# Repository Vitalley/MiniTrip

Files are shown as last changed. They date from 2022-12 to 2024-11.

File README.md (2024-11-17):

# MiniTrip
Miniature trip computer for Audi 80/100/200/A6C4 on PIC16F1847 with display SH1109/SSD1306/SSD1309 OLED controllers 128x64 pixel

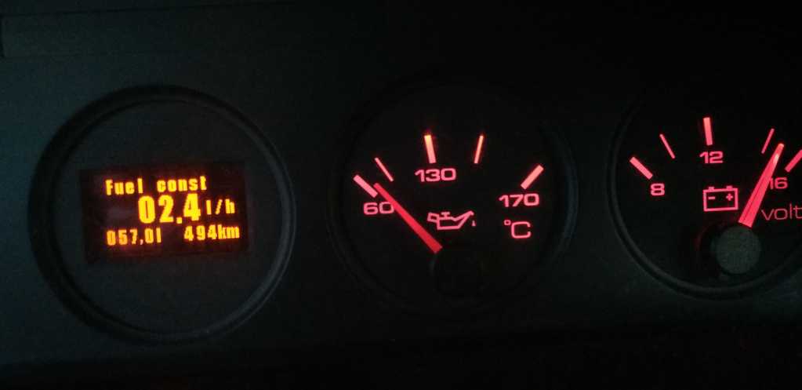
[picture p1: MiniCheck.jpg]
MiniCheck

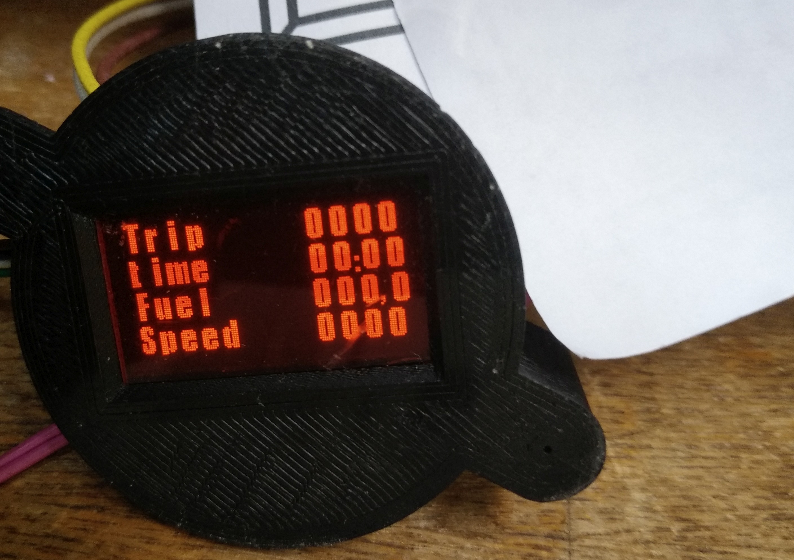
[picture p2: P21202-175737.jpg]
Test View


Main feutures:
- fuel consumption;
- speedometer;
- odometer;
- hour counter;
- on-board voltage;
- fuel level.

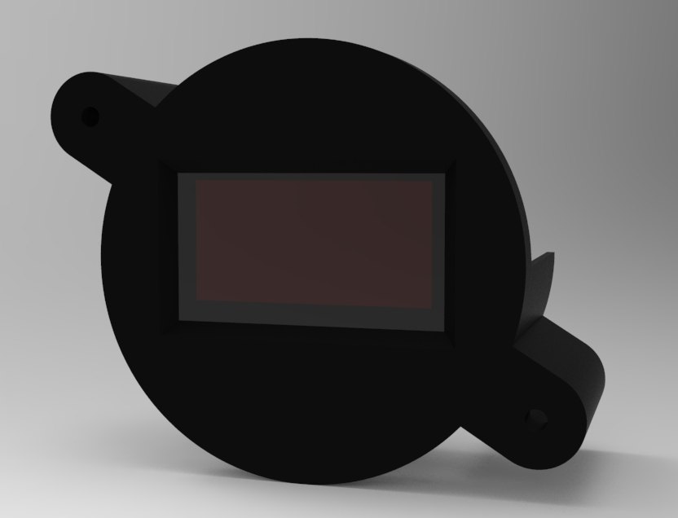
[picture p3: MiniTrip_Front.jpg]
Front

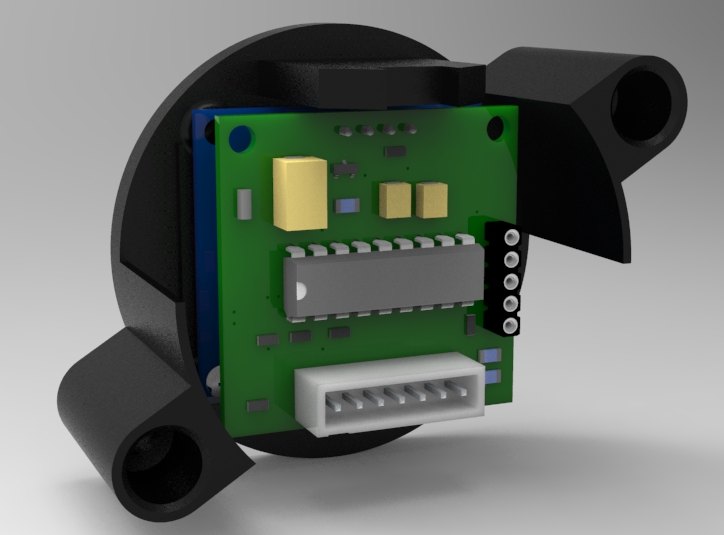
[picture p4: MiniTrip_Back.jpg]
Back


Testing on Audi A6/100 C4 with Digifant ECU ABK motor and AAD Motronic.

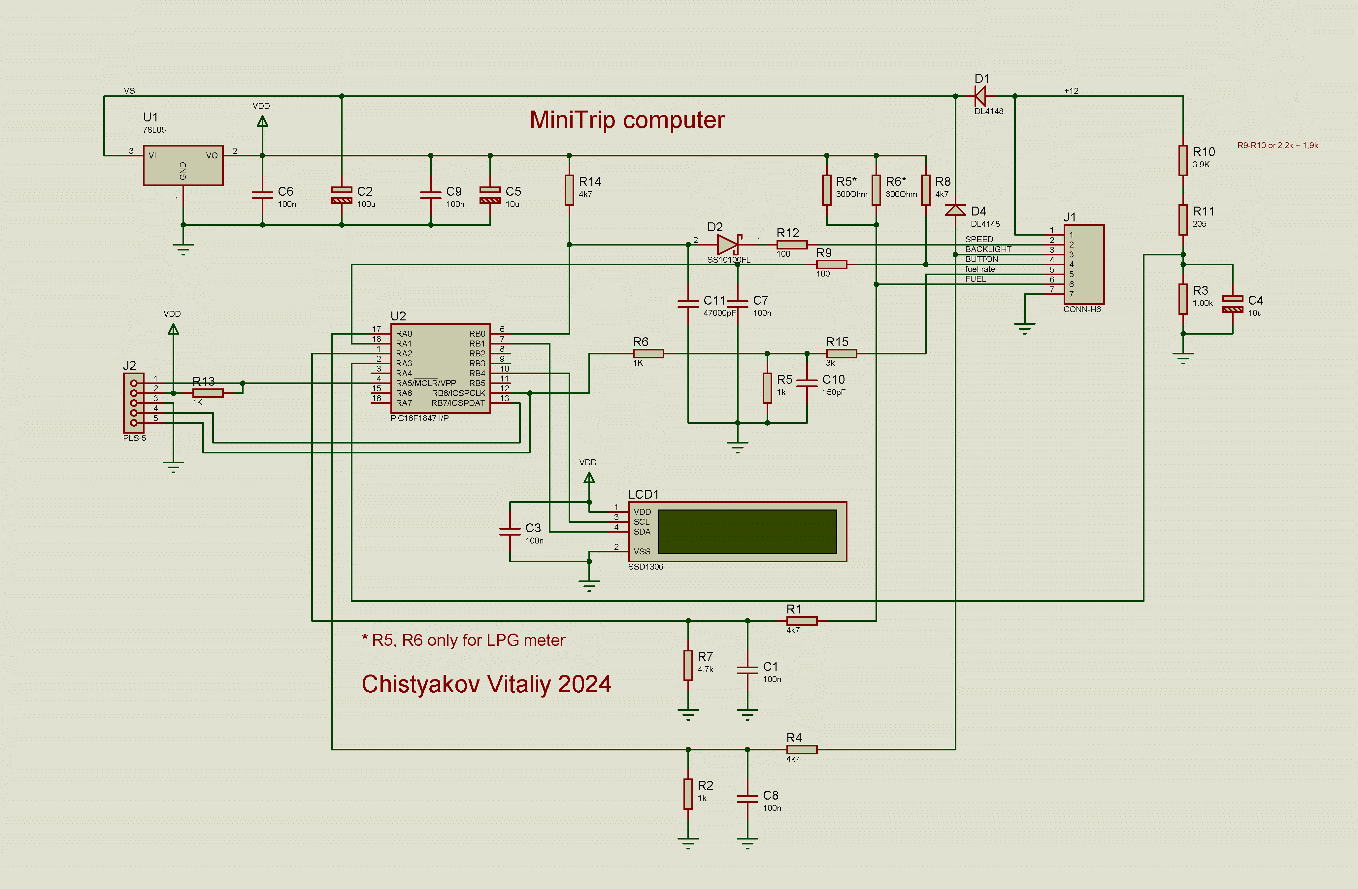
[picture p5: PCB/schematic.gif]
Schem


Fuel level sensor

|Fuel	|	Voltage|
|-----	|---		|
|12L	| 	- 2,4v|
|20L	|	- 3,0v|
|40L	|	 - 3,8v|
|60L	|	 - 4,5v|
|80L	|	 - 5,5v|

Project create in MPLAB IDE v8.92 from Mictochip and XC8 Compiler

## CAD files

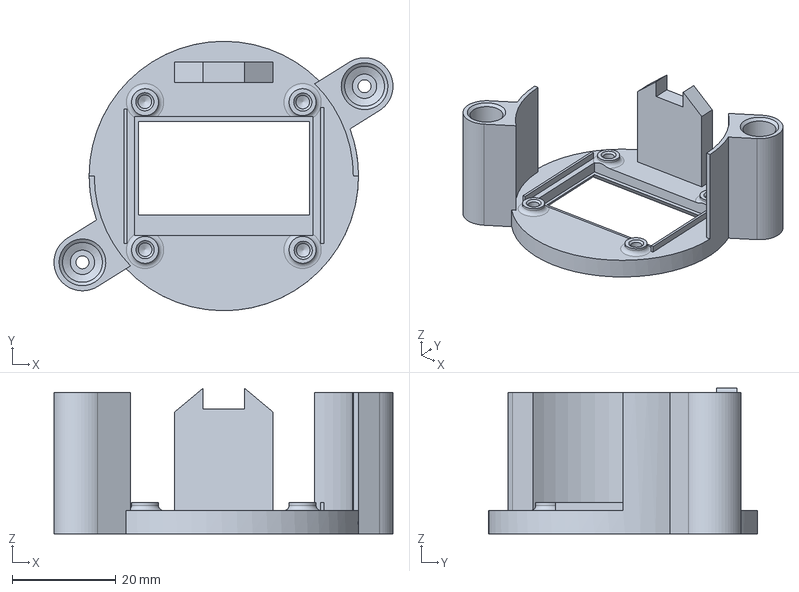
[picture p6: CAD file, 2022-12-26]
CAD/OLED_mask.stp
65.4 x 52.0 x 28.1 mm

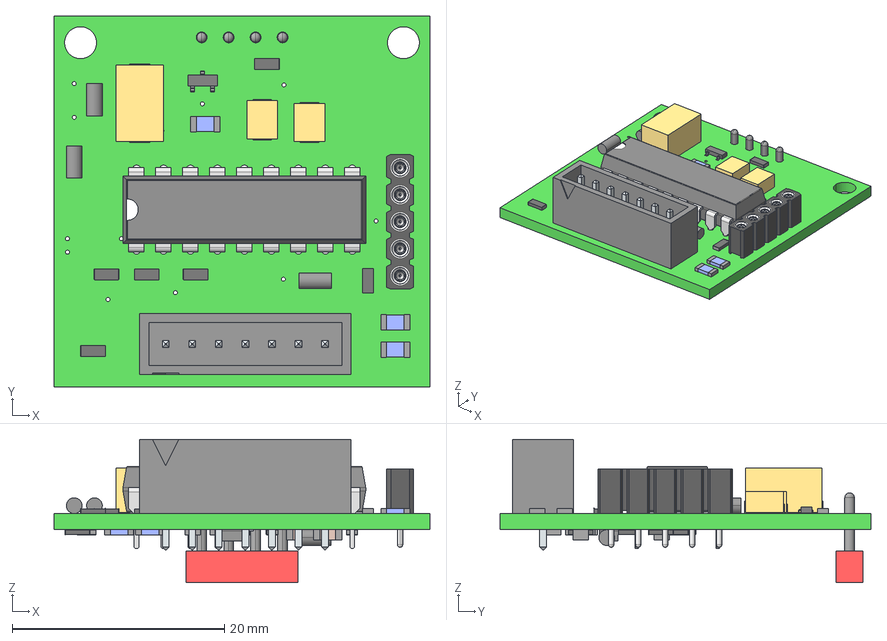
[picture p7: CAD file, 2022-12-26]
CAD/MiniTrip.STEP
35.4 x 34.9 x 13.5 mm
Layer_1
Pin_1 x 30
Pin_2 x 30
Pin_3 x 2
Pin_4
=>[0:1:1:2] x 2
=>[0:1:1:3]
=>[0:1:1:4]
=>[0:1:1:5]

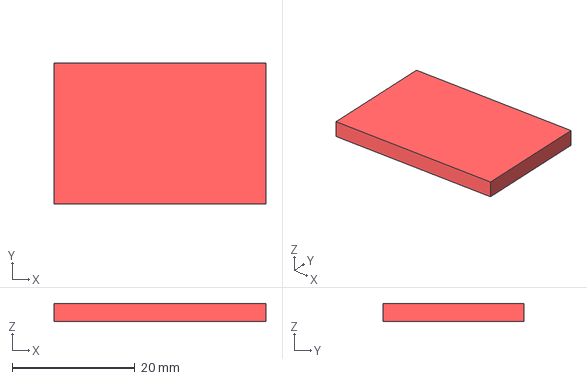
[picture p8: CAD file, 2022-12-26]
CAD/Glass.stp
34.5 x 23.0 x 3.00 mm

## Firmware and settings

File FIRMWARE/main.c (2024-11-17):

#include <xc.h>
//#include <stdio.h>
#include "../SH1106/OLED.h"
#include "screens.h"
#include "button.h"
#include "config.h"
#include "screen.h"
#include "I2C.h"
#include "EEPROM.h"
//#include "median.c"
/*
fuel -  расход топлива 0.1литр в час
speed - скорость км/ч*2
impavr - израсходовано топлива за поездку 25000/литр
triptime - время в пути Сек
fueltank - количество топлива в баке *10 л
*/
unsigned int  fuel, speed, speedcnt, fueltank, volt, volt_array[array_size_voltage+2], fuel_array[array_size_fuel+2];
unsigned long int impavr, trip, triptime, totalodo, totaltime, TO1_ODO, TO1_TIME, TO2_ODO, TO2_TIME;
bit turn = 0, motoron = 0, saveEEDATA = 0, bri;
static unsigned int TMR1_OLD_DATA = 0;
char scrn, mscr, mkey;
void init(void)
{
    LATA = 0x00;
    LATB = 0x00;
    TRISA = 0b00011111;
    TRISB = 0b01111111;
    ANSELB = 0x00;
    ANSELA = 0b0001101;
    WPUB = 0x00;
    WPUA = 0x00;
    OPTION_REGbits.nWPUEN = 1;
    APFCON0 = 0x00;
    APFCON1 = 0x00;
//	CPSCON0 = 0x00;

    OSCCON = 0x70;
    BORCON = 0x00;
//     OSCTUNE = 0x00;
     WDTCON = 0x16;
    while(PLLR == 0)
    {
	    CLRWDT();
    }
    I2CInit();
    OPTION_REG = (unsigned char)((OPTION_REG & 0xC0) | (0xD7 & 0x3F)); 
    TMR0 = 176;   
     //T1GSS T1G_pin; TMR1GE disabled; T1GTM disabled; T1GPOL low; T1GGO done; T1GSPM disabled; 
    T1GCON = 0x00;
    TMR1H = 0x00;
    TMR1L = 0x00;
    PIR1bits.TMR1IF = 0;  
    T1CON = 0b10000011; 
    T1GCON = 0;
    // Set TMR2 to the options selected in the User Interface
    PR2 = 0x03;
    TMR2 = 0x00;
    // Clearing IF flag before enabling the interrupt.
    PIR1bits.TMR2IF = 0;
    // Enabling TMR2 interrupt.
    PIE1bits.TMR2IE = 1;
    // T2CKPS 1:64; T2OUTPS 1:1; TMR2ON on; 
    T2CON = 0x07;
 
    
    ADCON1 = 0xF0;
    ADRESL = 0x00;
    ADRESH = 0x00;
    ADCON0 = 0x01;


    INTCONbits.TMR0IF = 0;
    INTCONbits.TMR0IE = 1;
    
    
    EEREADDATA();
    CLRWDT();
    _delay(1999);
    OLEDinit(OLED_Adr,127,62);    
    OLEDbrightness(OLED_Adr,0xF0); 
    bri = 1;
    
    
    // Enable IOCI interrupt 
    INTCONbits.IOCIE = 1; 
    INTCONbits.GIE = 1;
    INTCONbits.PEIE = 1;
}
unsigned int GET_ADC(char channel)
{
	__delay_us(100);
	ADCON0bits.CHS = channel;
	__delay_us(100);
	ADCON0bits.GO_nDONE = 1;
	while (ADCON0bits.GO_nDONE){}
	return ((unsigned int)((ADRESH << 8) + ADRESL));
}
unsigned int SMA_filter(unsigned int a,unsigned  int* Massive, unsigned char array_size)
{
	char n=Massive[array_size];
	if (n>=(array_size)) n=0;	
	Massive[n]=a;
	Massive[array_size]=n+1;
	if (Massive[array_size+1] < array_size-1) {Massive[array_size+1]++;return (a);}
	a=0;
	for(char j=0;j<array_size;j++) 
	{
		a=a+Massive[j];
	}
	return (unsigned int)a/array_size;
}
unsigned int map(unsigned int x, unsigned int in_min, unsigned int in_max, unsigned int out_min, unsigned int out_max)
{
  return (x - in_min) * (out_max - out_min) / (in_max - in_min) + out_min;
}
void main(void)
{
	static char seladc;
	init();
	fueltank = 100;
    _delay(999);CLRWDT();
 	oledClear(OLED_Adr);
 	screen0();
 	for (int bra=0;bra<5600;bra++)
	{
		_delay(1999);CLRWDT();	
	}

 	mscr = 0;speed=0;fuel=0;seladc=0;


while(1)
{
	CLRWDT();
switch (seladc)
{
case 0:	if (GET_ADC(0) > 200) 
	{
		if (bri !=0 ) {OLEDbrightness(OLED_Adr,0x00); bri = 0;}
	}	 
	else 
	{
		if (bri != 1 ) {OLEDbrightness(OLED_Adr,0xFF); bri = 1;}
		
	}
	seladc++;	
	break;
case 1:	volt = SMA_filter(GET_ADC(3), volt_array, array_size_voltage);
	seladc++;
	break;
case 2:	fueltank = SMA_filter(GET_ADC(2), fuel_array, array_size_fuel);
	//fueltank = Wquick_select_median(fuel_array, array_size_fuel);
	fueltank = fueltank - ft_sdd;
	//fueltank = 183;
	fueltank = (fueltank * (unsigned long int)ft_mult)/256;
	if (fueltank < 1000) fueltank = 1000 - fueltank; else fueltank = 0;
	if (fueltank > 999) {fueltank = 999;}
	seladc=0;
	break;
default: seladc=0;
}
	if (saveEEDATA) {EEWRITEFATA(); saveEEDATA=0;}
	if (speed>10) turn=1; else turn=0;
	if (fuel>1) motoron=1; else motoron=0;
CLRWDT();
	switch (mscr)
	{
	case 0: 	
	
		if (turn)
		{
			if (scrn != 1)oledClear(OLED_Adr);
			screen1();
				
		}
		
		else
		
		{
			if (motoron)
			{
		 	 	if (scrn != 2)oledClear(OLED_Adr);
				screen2();
			 		
			}
		 	else
			{
		 		if (scrn != 4)oledClear(OLED_Adr);
				screen4();
			}
		
		}
		break;
// Текущая скорость движения	
	case 1:	
		if (!turn) 	
		{ 
			if (!motoron) {mscr++; break;}
		}
		if (scrn != 3) oledClear(OLED_Adr);
		screen3();
		break;
// Общая сводка о пройденом пути	
	case 2:
		if (!turn)
		{ 
			if (!motoron) {mscr++; break;}
		}	
		if (scrn != 4) oledClear(OLED_Adr);
		screen4();
		break;
// Бортовое напряжение	
	case 3:
		if (volt<40) {mscr++; break;}
		if (scrn != 6) oledClear(OLED_Adr);
		screen6();
		break;
//	Уровень топлива в баке и остаток пути	
	case 4:
		if (volt<10 || fueltank==0) {mscr++; break;}
		if (scrn != 7) oledClear(OLED_Adr);
		screen7();
		break;
// TO1	
	case 6:
		if (turn) {mscr++; break;}
		if (scrn != 8) oledClear(OLED_Adr);
		screen8();
		break;
// TO2	
	case 7:
		if (motoron) {mscr++; break;}
		if (scrn != 9) oledClear(OLED_Adr);
		screen9();
		break;
// Общий пробег
	case 5:
		if (motoron) {mscr++; break;}
		if (scrn != 5) oledClear(OLED_Adr);
		screen5();
		break;	
	default:
		scrn = 0;
	}
	 for (int bra=0;bra<24;bra++)
		{
			_delay(30000);CLRWDT();
			mkey = GetButton();
		
			if (mkey == 2)
			{ 
				if (mscr == 6)
				{
					screen11();
					for (unsigned char bra=0;bra<250;bra++)
					{
						mkey = GetButton();
						_delay(40000);
						if (mkey == 1) {EETO1RESET();}
					}
				}
				else if (mscr == 7) 
				{
					screen12();
					for (unsigned char bra=0;bra<250;bra++)
					{
						mkey = GetButton();
						_delay(40000);
						if (mkey == 1) {EETO2RESET();}
					}		
				}
				else 
				{
					screen10();
					for (unsigned char bra=0;bra<250;bra++)
					{
						mkey = GetButton();
						_delay(40000);
						if (mkey == 1) {EETRIPRESET();}
					}			
				}
			}
			else if (mkey == 1) mscr++;
			
			if (mscr > 7) mscr=0;	
		}
}
}


void TMR0_ISR(void)
{
    static unsigned int CountSeconds = 0, Count7n2Seconds = 0, CountSPD = 0;
    static unsigned char CountTripTime;
    // callback function - called every 391th pass
    //	 Секундный счётчик
    if (++CountSeconds >= 391)
    {
	CountSeconds=0;
	// 30 Секундный счётчик
	if (++CountTripTime >= 30)
    	{
		if (fuel>1 || speed>1)
		{
			triptime++;
			totaltime++;
			TO1_TIME++;
			TO2_TIME++;
		}
		CountTripTime=0;
		saveEEDATA=1;
    	}
	
    }
// Счётчик для измерения расхода топлива
    if (++Count7n2Seconds >= 563)//563 при 25000 имп/литр
    {
// Код не вместился в память
//	char TMPH, TMPL;
//	do
//	{
//		TMPH = TMR1H;
//		TMPL = TMR1L;
//	}
//	while (TMPH == TMR1H);
//	unsigned int TMR_DATA = TMPH <<8 + TMPL;
	unsigned int TMR_DATA = TMR1;
	unsigned int FUEL = TMR_DATA - TMR1_OLD_DATA;
	TMR1_OLD_DATA = TMR_DATA;
	fuel = FUEL;
	impavr+=FUEL;
	Count7n2Seconds=0;
    }
// Счётчик скорости движения
    if (++CountSPD >= 698)
    {
	CountSPD = 0; 
	speed = speedcnt;
	speedcnt = 0;
    }
}
void TripCounter(void)
{
    static volatile unsigned int CountKM = 0;
    speedcnt++;
    if (++CountKM >= 409) // 100 метровый счётчик
    {
	trip++; 
	totalodo++;
	TO1_ODO++;
	TO2_ODO++;
	CountKM = 0;
    }
}
void interrupt isr(void)
{
   if(INTCONbits.INTF)
    {
	    INTCONbits.INTF = 0;
	    INTCONbits.INTE = 0;
	    T2CONbits.TMR2ON = 1;
	       	if (OPTION_REGbits.INTEDG) 
		        {
			        TripCounter();
			        OPTION_REGbits.INTEDG = 0;

			     }
	        else     
		        {
			        OPTION_REGbits.INTEDG = 1;
	        	}
	}
    else 
    if(PIR1bits.TMR2IF)
    {
    		PIR1bits.TMR2IF = 0;
    		T2CONbits.TMR2ON = 0;
    		INTCONbits.INTE = 1;
			TMR2 = 0;
    }
    else 
	if(INTCONbits.TMR0IF)
	{
		TMR0 = 176;
		INTCONbits.TMR0IF = 0;
		TMR0_ISR();
	}


}

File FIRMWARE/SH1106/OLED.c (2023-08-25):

#include <xc.h>
//#include <stdio.h>
#include "../I2C.h"
#include "OLED.h"
#define OLED_Adr 0x3C
#include "Font16x8.h"
#include "Font40x20.h"
void oledCommand(unsigned char comm, unsigned char Adr) {
	StartI2C();
	if (WriteI2C( (Adr<<1) & 0xFE)!=0) return;//Начинаем передачу команд устройству с адресом Adr.
  	WriteI2C(0x00);//Сообщаем дисплею, что следующее передаваемое значение - команда.
  	WriteI2C(comm);//Передаем команду.
  	StopI2C();//Завершаем передачу данных.
 }
void oledData(unsigned char data,unsigned char Adr) {
	StartI2C();
 	if (WriteI2C( (Adr<<1) & 0xFE)!=0) return;//Начинаем передачу команд устройству с адресом Adr.
	WriteI2C(0x40);//Сообщаем дисплею, что следующее передаваемое значение - данные, которые необходимо вывести на дисплей.
 	WriteI2C(data);//Передаем данные.
 	StopI2C();//Завершаем передачу данных.
}
void oled_DataBurst(unsigned char data[],unsigned char Adr,unsigned char size)
{
	StartI2C();
	if (WriteI2C( (Adr<<1) & 0xFE)!=0) return;//Начинаем передачу команд устройству с адресом Adr.
	WriteI2C(0x40);//Сообщаем дисплею, что следующее передаваемое значение - данные, которые необходимо вывести на дисплей.
 	
 	for (char k=0; k < size; k++)
 	{
 		WriteI2C(data[k]);//Передаем данные.
 	} 
 	StopI2C();//Завершаем передачу данных.	
}
unsigned char oledRead(unsigned char Adr)
{
	StartI2C();
 	if (WriteI2C( (Adr<<1) & 0xFE)!=0) return(0);//Начинаем передачу команд устройству с адресом Adr.
	WriteI2C(0x40);//Сообщаем дисплею, что следующее передаваемое значение - данные, которые необходимо вывести на дисплей.
 	unsigned char dat = ReadI2C();//Передаем данные.
 	StopI2C();//Завершаем передачу данных.
 	return(dat);
}
void OLED_set_x (unsigned char x,unsigned char Adr)
{
	oledCommand(0x0f & (x),Adr);//set column addr 4 lower 
	oledCommand(0x10|(x>>4),Adr);//set column addr 4 higher 
	return;
}
void OLED_set_y (unsigned char y,unsigned char Adr)
{
	oledCommand(0xB0 ^ (y & 0x0F), Adr);
}
void OLED_set_XY (unsigned char x,unsigned char y,unsigned char Adr)
{
	oledCommand(0x0f & (x),Adr);//set column addr 4 lower 
	oledCommand(0x10|(x>>4),Adr);//set column addr 4 higher 
	oledCommand(0xB0 ^ (y & 0x0F), Adr);
}
void oledClear(unsigned char Adr) //Эта функция очищает дисплей.
{
const unsigned char page = 0xB0;
	for(unsigned char y = 0; y < 8; y++) 
	{
		oledCommand(page+y, Adr);
		OLED_set_x(2, Adr);
		StartI2C();
		if (WriteI2C( (Adr<<1) & 0xFE)!=0) return;//Начинаем передачу команд устройству с адресом Adr.
		WriteI2C(0x40);//Сообщаем дисплею, что следующее передаваемое значение - данные, которые необходимо вывести на дисплей.
		for(unsigned char x = 0; x < 128; x++)
		{
		//	oledData(0x00, Adr);
			 WriteI2C(0x00);
		}
		StopI2C();//Завершаем передачу данных.
	}
}


void OLEDinit(unsigned char Adress,unsigned char x_size, unsigned char y_size) { 
//процесс инициализации честно скопирован из даташита на дисплей.
 	oledCommand(0xAE,Adress);//выключение дисплея
	oledCommand(0xD5,Adress);//Set Display Clock Divide Ratio/Oscillator Frequency
	oledCommand(0x80,Adress);//(00H - 3FH)
	oledCommand(0xA8,Adress);// Multiplex Ration Mode Set: (A8H)
	oledCommand(y_size,Adress);//00 Multiplex Ration Data Set: (00H - 3FH)
	oledCommand(0xD3,Adress);
	oledCommand(0x00,Adress);
	oledCommand(0x00,Adress);//Младшие биты адреса колонки
	oledCommand(0x10,Adress);//Старшие биты адреса колонки 
	oledCommand(0x40,Adress);//Стартовая строка: (40H - 7FH)
	oledCommand(0xB0,Adress);//Стартовая страница	
	oledCommand(0x8D,Adress);//включение емкостного умножителя
//	oledCommand(0x14,Adress);
	oledCommand(0x20,Adress);//настройка адресации
	oledCommand(0x00,Adress);// 0х00 для горизонтальной, 0х01 для вертикальной, 0х02 для постраничной адресации
	oledCommand(0xA1,Adress);//отражение по горизонтали, для отображения справа налево необходимо использовать команду 0xA0 (A0H - A1H)
	oledCommand(0xC8,Adress);//отражение по вертикали, 0xC0 для переворота изображения по вертикали.
//Одновременное использование команд 0xC8 и 0xA1 или 0xA0 и 0xC0 позволяет повернуть изображение на 180 градусов.
	oledCommand(0xDA,Adress);// Common Pads Hardware Configuration Mode Set: (DAH)
	oledCommand(0x12,Adress);//Sequential/Alternative Mode Set: (02H - 12H) 
	oledCommand(0x10,Adress);//установка контрастности дисплея
	oledCommand(0xCF,Adress);//Контрастность (00-FFh)
	oledCommand(0xD9,Adress);//Pre-charge Period Mode Set: (D9H) 
	oledCommand(0x1F,Adress);//  Dis-charge/Pre-charge Period Data Set: (00H - FFH)
	oledCommand(0xDB,Adress);// VCOM Deselect Level Mode Set: (DBH)
	oledCommand(0x40,Adress);//VCOM Deselect Level Data Set: (00H - FFH)
	oledCommand(0xA4,Adress);// Set Entire Display OFF/ON: (A4H - A5H)
	oledCommand(0xA6,Adress);//инверсия дисплея, 0xA6 для отключения инверсии, 0xA7 для включения инверсии цвета. Set Normal/Reverse Display: (A6H -A7H)
	oledCommand(0xAF,Adress);//включение дисплея
	//IdleI2C();
//	oledClear(Adress);//Используем функцию очистки дисплея.
}
void OLEDbrightness(unsigned char Adress, unsigned char Brtns)
{
	oledCommand(0x81,Adress);
	oledCommand(Brtns,Adress); //Контрастность (00-FFh)
}
void OLEDdrawbar(unsigned char Adress, unsigned char y, int val)
{
	OLED_set_y(y ,Adress);
	OLED_set_x (0, Adress);
	for(unsigned char x = 0; x < 132; x++)
	{
	if (x<val)	{oledData(0xFF,Adress);} else {oledData(0x00,Adress);}
	}
}
void OLEDdrawcol(unsigned char Adress, unsigned char x, int val)
{
	for(unsigned char y = 2; y < 7; y++)
	{
		OLED_set_x (x, Adress);
		OLED_set_y (y ,Adress);
		char S=0, C=0,str[14];
		for (char n=0;n<8;n++)
		{
			char D=n+((y-2)*8);
			if ( ((D> val) & (D<19)) | ((D< val) & (D>20)) ) S = S|(1 << n); 				
		}
		for(unsigned char d = 0; d < 14; d++)
		{
			if (y == 4)  {C = 0x18;}else{C = 0;}
			//if (d > 4 && d < 11){oledData(S|C,Adress);}else{oledData(C,Adress);}
			if (d > 4 && d < 11){str[d]=S|C;}else{str[d]=C;}
			
		}
		oled_DataBurst(str,Adress,14);
	}	
	
}
void drawPixel(unsigned char x, unsigned char y, unsigned char color)
{
//if ((x < 0) || (y < 0) || (x >= _width) || (y >= _height)) return;



}
void PutChar_mid(unsigned char x,unsigned char y,unsigned char dig,unsigned char Adress) //
{
	unsigned char i=0,pitch=0x21, str[12]; 
	if( dig<pitch ){dig=45;}
	if( dig>=0x7F ){dig=45;}
	OLED_set_x (x, Adress);OLED_set_y (y, Adress);
	for(i=1; i<13; i++) {str[i-1]=(font_16x8_data_table[dig-pitch][i]);}
	oled_DataBurst(str, Adress, 12);
	OLED_set_x (x, Adress);OLED_set_y (y+1, Adress);	
	for(i=13; i<24; i++) {str[i-13]=(font_16x8_data_table[dig-pitch][i]);}
	oled_DataBurst(str, Adress, 12);
}
void PutStr_mid(unsigned char x, unsigned char y, const char txt[],unsigned char Adr)
{
	unsigned char i=0;
	while (txt[i]!=0 & i<32)
	{
		PutChar_mid(x+i*10,y,txt[i],Adr);
		i++;
	}
	return;
}
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

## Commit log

2022-12-26 Fix bug & new function
    [Screens.c]
2022-12-26 Оформление
2022-12-26 CAD files
    [Glass.stp, MiniTrip.STEP]
2023-02-16 Исправления расхода
    Исправления показаний расхода топлива, добавлена возможность корректировать показания расхода топлива через определение impilse_per_litre
    [Screens.c, main.c]
2023-04-13 Обновление
    Не большие обновления и исправления
    [Screens.c, main.c]
2023-08-25 Доработка проекта
    Исправлены некоторые ошибки, улучшена обработка сигналов, убраны варнинги.
    [OLED.c, Screens.c]
2023-10-26 Update schematic.gif
    Исправлены номиналы сопротивлений в делителе напряжения
2024-06-28 Fix EEPROM stability
    Добавлена двойная запись в постоянную память, если произойдёт сбой во время записи одной ячейки, то данные будут доступны в её копии
    [Screens.c, main.c]
2024-11-17 Vers 1.1
    + Добавлен подавитель дребезга для контактного датчика скорости.
    + Добавлена работа через триггер Шмидтта и аппаратный таймер для учёта расхода топлива.
    Соответственно изменена обработка прерываний.
    Сигнал расхода теперь подаётся на другой врод микроконтроллера.
